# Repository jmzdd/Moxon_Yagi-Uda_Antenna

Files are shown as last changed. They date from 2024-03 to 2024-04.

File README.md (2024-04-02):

# <p align="center">Moxon+Yagi Antenna</p>

<p align="center">⚠实验性：天线尚未经过矢量网络分析仪测量，仅通过MMANA-GAL仿真。</p>
<p align="center">😮复刻有风险，制作需谨慎🤭</p>

## 一、项目背景

&emsp;&emsp;本天线设计参考了“Moxon-Yagi Satellite Antenna by DUIAU (based LY3LP's design)”，感谢DU1AU和LY3LP两位前辈的贡献，原设计图如下：

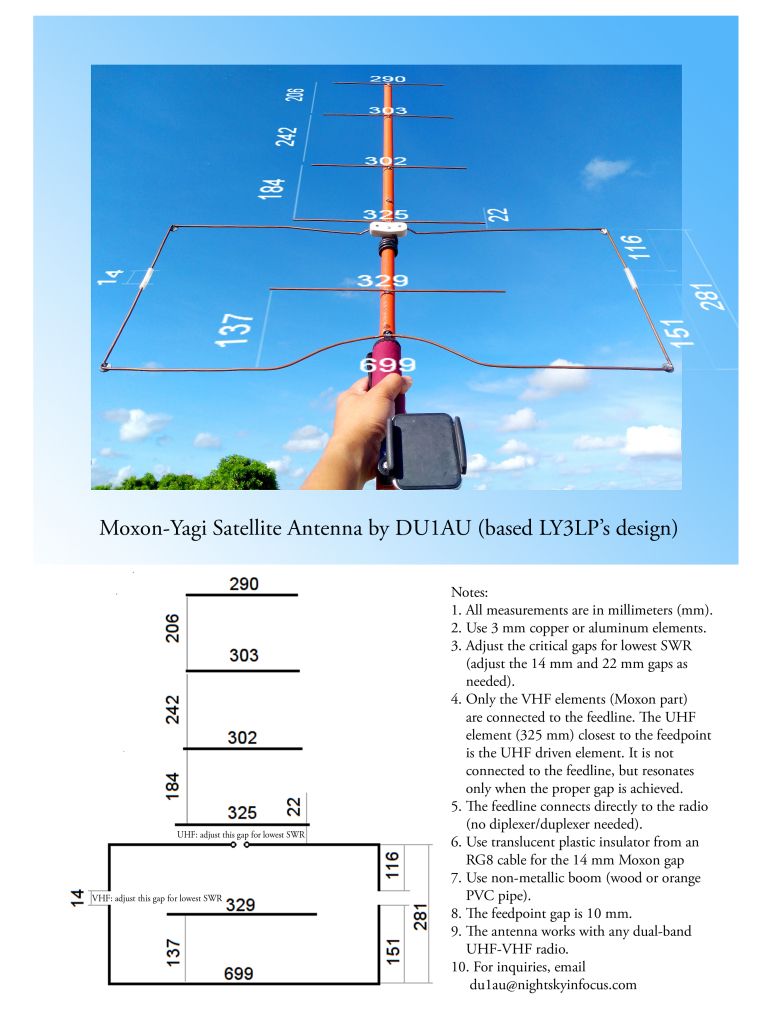
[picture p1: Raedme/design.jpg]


&emsp;&emsp;由于本人手上只有直径1.25mm的铜线作为振子，因此需要对天线的尺寸重新设计。这里我选择使用MMANA-GAL软件对天线进行仿真。花了一两天时间在B站熟悉和理解软件的使用，最后根据软件的仿真结果制作出了成品。

## 二、设计过程

### 2.1 设计思路
&emsp;&emsp;因为是UV双段天线，因此要求天线的中心频率在常用的两个频段：145MHz与435MHz。使用软件对该天线进行仿真，在结构不变的前提下，我修改了振子的长度与各振子之间的间距，最终得出了想要的结果。

&emsp;&emsp;先使用Moxon天线计算器计算莫克森部分，确定其振子的尺寸。由于没有找到合适的八木计算器，无法直接计算八木部分的振子尺寸和间距，遂在确定了莫克森振子尺寸之后在MMANA-GAL软件内建模仿真，通过不断调整八木振子的长度和距离，反复计算其在435MHz时的阻抗和驻波比，最终确定其尺寸和距离。

### 2.2 MMANA-GAL软件仿真

+ 建立天线模型：
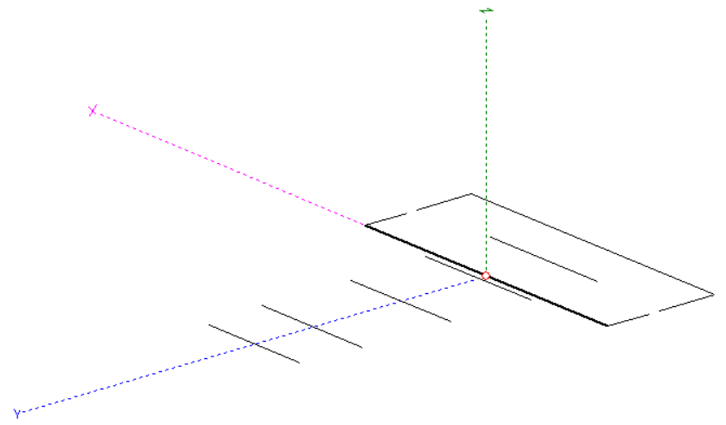
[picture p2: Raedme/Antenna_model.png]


+ 调整八木天线的振子长度和距离：
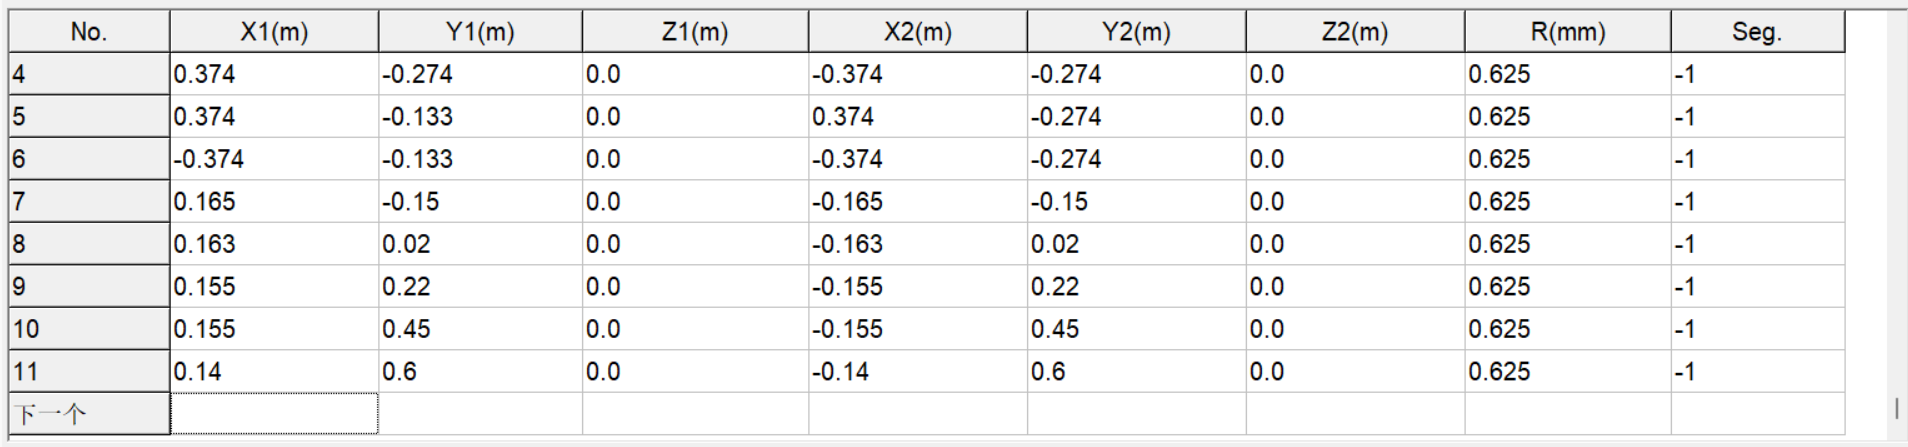
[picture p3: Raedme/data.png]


+ 计算天线阻抗以及驻波比：
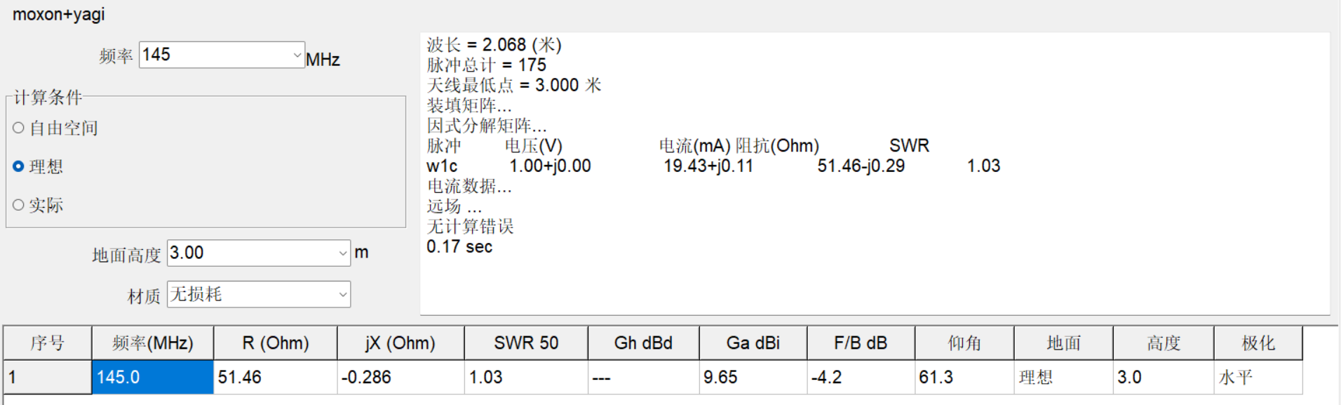
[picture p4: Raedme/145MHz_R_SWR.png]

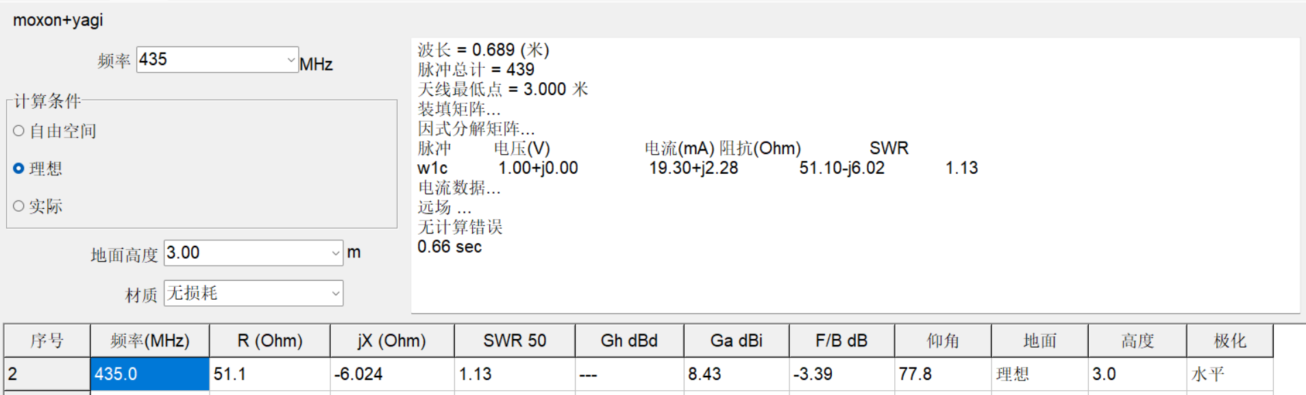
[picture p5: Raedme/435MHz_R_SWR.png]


+ 145MHz与435MHz的远场图：
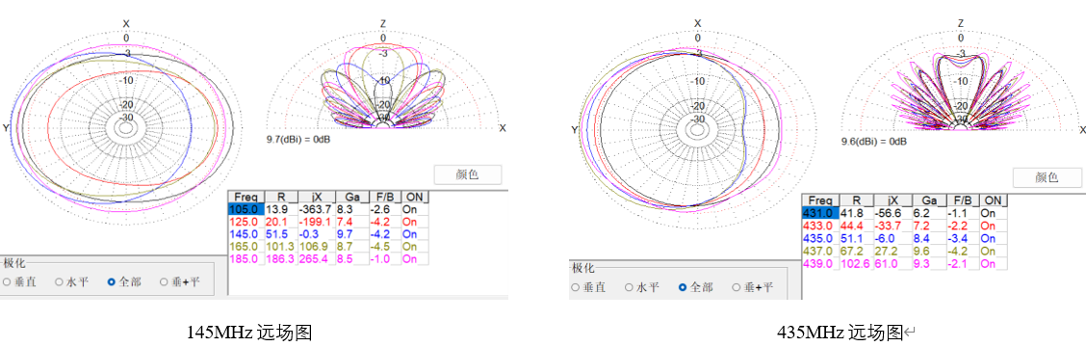
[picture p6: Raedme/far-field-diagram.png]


&emsp;&emsp;由于理论知识欠缺的实在多，在设计过程中遇到的问题大多交给Gemini帮忙给出建议，例如：要解决天线阻抗偏小的问题，可以采取以下措施：
+ 增加天线的尺寸。天线的尺寸越大，天线的输入阻抗就越高。
+ 缩短馈电点的长度。馈电点的长度越短，天线的输入阻抗就越高。
+ 添加串联电感。串联电感可以提高天线的输入阻抗。

&emsp;&emsp;经过调整后，软件显示天线在145MHz的时候，其阻抗为51.46欧姆，驻波比为1.03;当频率为435MHz时，其阻抗为51.1欧姆，驻波比为1.13。

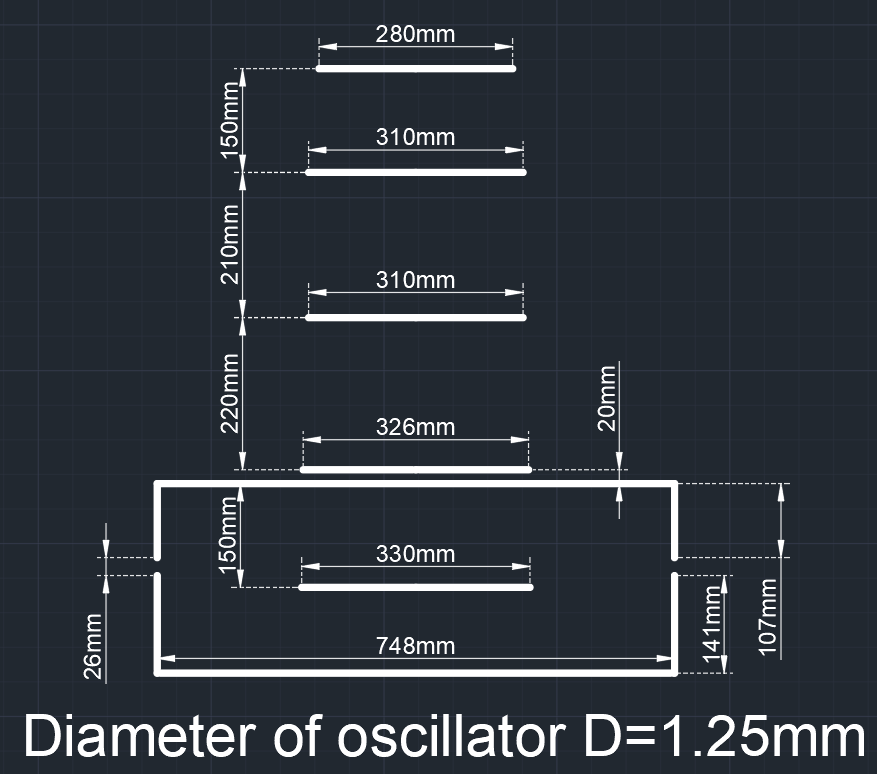
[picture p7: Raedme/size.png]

&emsp;
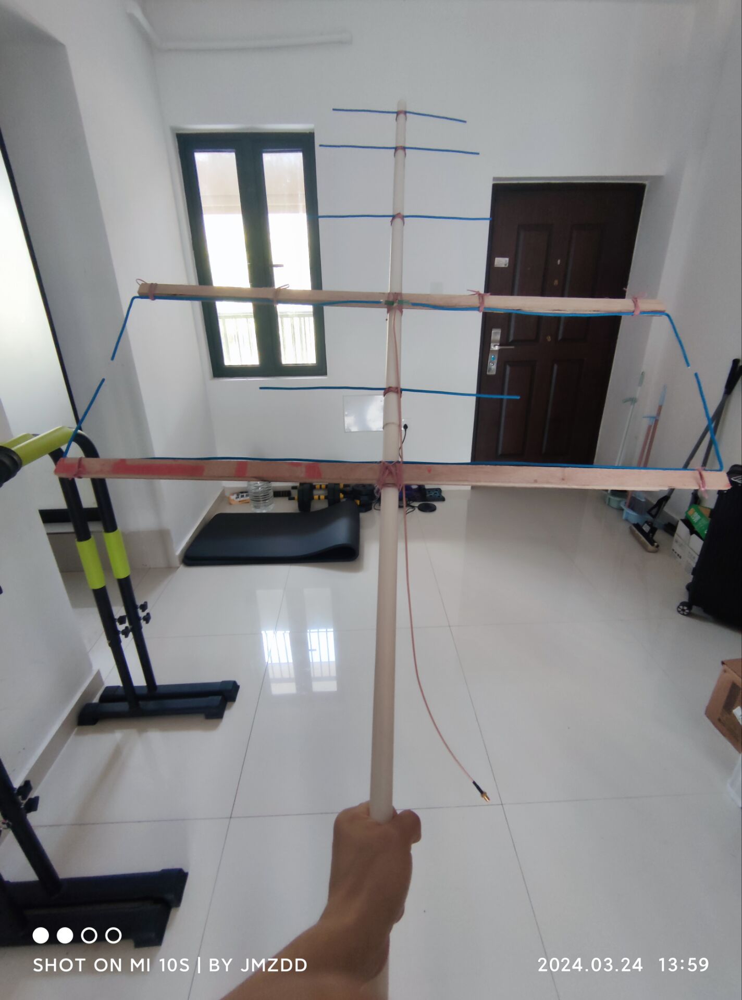
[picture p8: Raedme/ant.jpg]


## 三、文件说明
&emsp;&emsp;仓库内包含了我所使用的仿真软件安装包以及所有的仿真结果，软件资源来源自互联网。现对仿真文件进行说明：

| 文件名 | 说明  |
|:---:| :---:|
| moxon+yagi_d1.25mm.maa | 振子直径为1.25mm |
| moxon+yagi_d2mm.maa | 振子直径为2mm |
| moxon+yagi_d3mm.maa | 振子直径为3mm |

&emsp;&emsp;软件在使用过程中可能会出现“点击仿真不出结果”的情况，我没有找到原因。如果有知道原因的同学，欢迎联系我~

&emsp;&emsp;和老师交流期间做了一些框图文档啥的，存电脑也是浪费，顺带着一起上传了。

## 四、测试过程

&emsp;&emsp;⏰提示：在与学院老师的交流中得知，手台发射的信号属于调频信号，SDR瀑布图内看到的“多个信号”是正常的。如果要测量天线的中心频率，需要用单频信号来测，发射单纯435MHz的信号，在接收的时候才能判断是否是中心频率。（2024/3/20）

&emsp;&emsp;~~由于手上没有设备，因此使用了RTL-SDR进行测试，其中145MHz不明显，435MHz瀑布图如下：~~
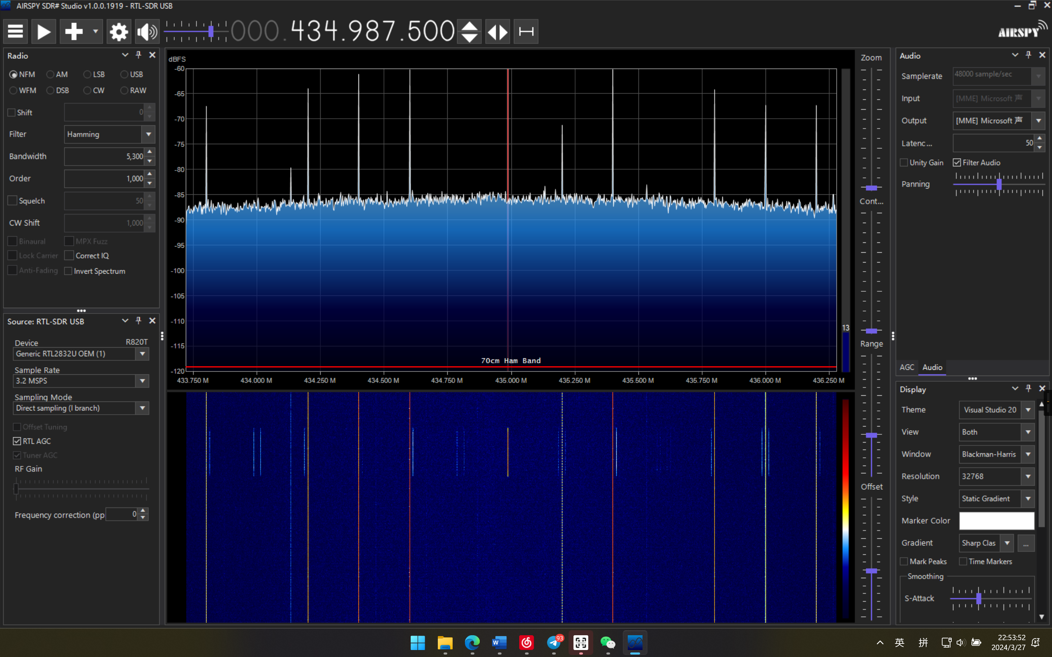
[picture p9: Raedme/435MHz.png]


## 五、制作材料
全天线制作成本为5.3元（可以说非常丐版，挑战全网最低成本天线）

来自食堂工地：
+ 天线支架：PVC水管+木条
+ 天线振子：直径为1.25mm的单股铜线
+ 连接固定：工地纸箱的打包带

淘宝自购：
+ 馈线：RG316，SMA外螺内孔，长度0.8m（5.3元）

## 六、参考资料
### 6.1 仿真软件学习
+ <a href="https://www.qsl.net/bv3fg/ant/MMANA-GAL_manual_zh-TW_20211206-01.pdf">【MMANA-GAL_manual_zh-TW.pdf】</a>
+ <a href="https://www.bilibili.com/video/BV14J411Q7TQ/?vd_source=4c90b194142aa9512e6e97d2155ada5d">【宅台长】天线设计软件MMANA-GAL介绍</a>
+ <a href="https://www.bilibili.com/video/BV12Z4y1B7dj/?vd_source=4c90b194142aa9512e6e97d2155ada5d">【业余无线电·天线仿真】MMANA-GAL仿真：莫克森天线应该怎样调整</a>
### 6.2 天线计算器
+ <a href="https://upall.cn/example/moxon/">【天线计算器】</a>
### 6.3 调试与制作
+ <a href="https://www.hellocq.net/forum/read.php?tid=374264">DIY“莫克森+八木”UV双段天线</a>
+ <a href="https://www.bilibili.com/video/BV19v411T7gT/?vd_source=4c90b194142aa9512e6e97d2155ada5d">自己做一根UV段八木天线连接国际空间站转发器能成功吗？</a>

希望能够对看到这份文档的朋友提供一些小帮助，73~

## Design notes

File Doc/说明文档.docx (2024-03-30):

Moxon+Yagi-Uda UV双段天线设计说明

⚠实验性：天线尚未经过矢量网络分析仪测量，仅通过MMANA-GAL仿真。

复刻有风险，制作需谨慎

1、 项目背景

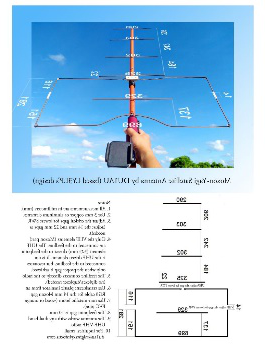
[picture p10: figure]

本天线设计参考了“Moxon-Yagi Satellite Antenna by DUIAU (based LY3LP's design)”，感谢DU1AU和LY3LP两位前辈的贡献，参考设计图见左图。

由于本人手上只有直径1.25mm的铜线作为振子，因此需要对天线的尺寸重新设计。这里我选择使用MMANA-GAL软件对天线进行仿真。花了一两天时间在B站熟悉和理解软件的使用，最后根据软件的仿真结果制作出了成品。

天线设计图

2、 设计过程

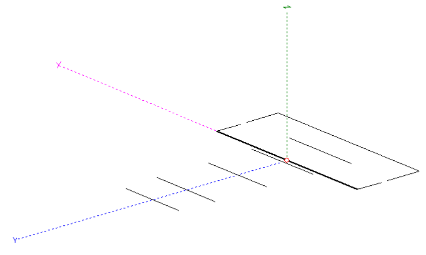
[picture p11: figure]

该天线主要分为莫克森部分以及八木部分，其中莫克森天线设计的中心频率在145MHz，其振子尺寸可以由天线计算器得出。在MMANA-GAL软件内对天线建模，通过调整八木部分的振子长度与间距，仿真其频率在435MHz时，使其天线阻抗接近50Ω，驻波比接近1。

天线模型

经过调整后，软件显示天线在145MHz的时候，其阻抗为51.46欧姆，驻波比为1.03;当频率为435MHz时，其阻抗为51.1欧姆，驻波比为1.13。

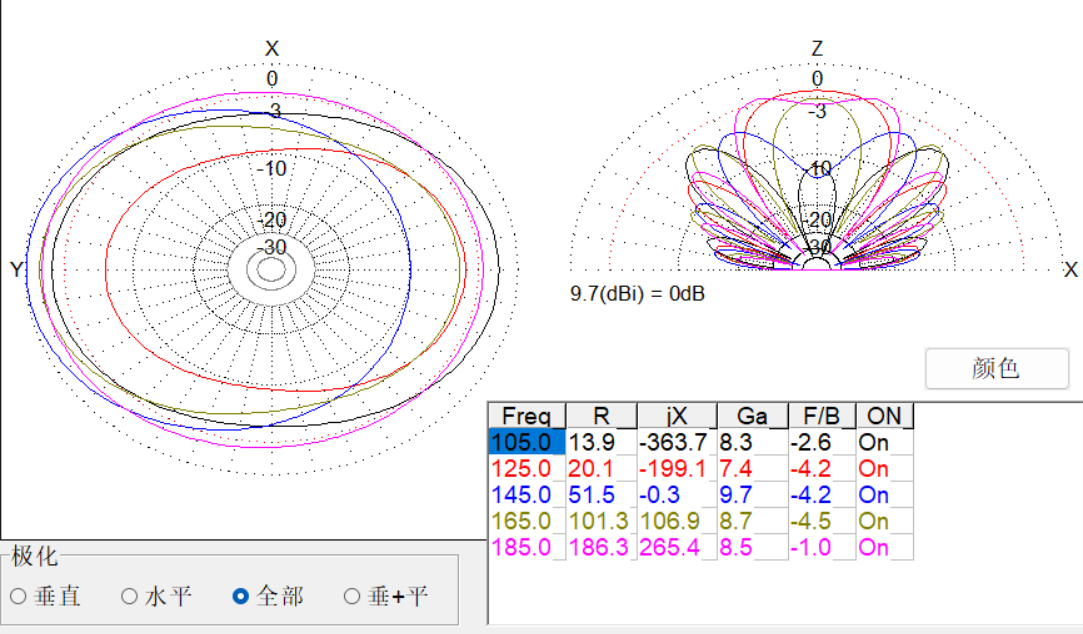
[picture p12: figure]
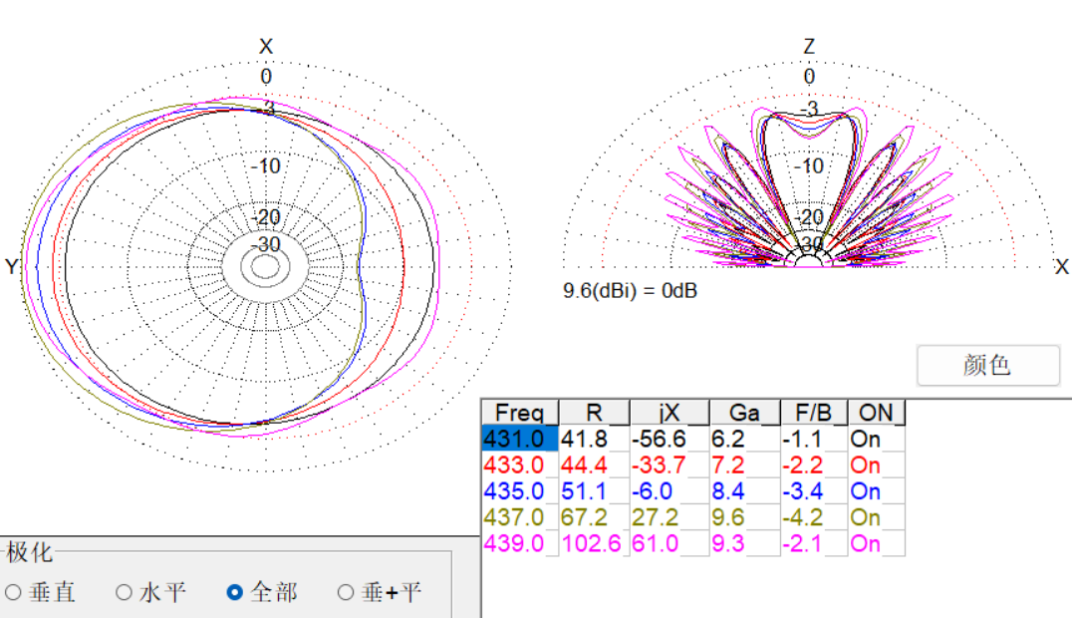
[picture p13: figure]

145MHz远场图 435MHz远场图

3、 项目总结

受制于材料、测试环境的限制以及理论知识的欠缺，该天线的性能仍有很大的优化空间。例如无法测量天线的驻波比以及天线阻抗，RTL-SDR测量到的中心频率并不完全准确等。天线的制作可能存在一定的尺寸误差，振子长度以及距离并不精确。在制作过程中省略了加感线圈，可能会导致天线阻抗误差较大。

4、 参考资料

见仓库Readme.md。

五、制作材料

全天线制作成本为5.3元（可以说非常丐版，挑战全网最低成本天线）

来自食堂工地：

天线支架：PVC水管+木条

天线振子：直径为1.25mm的单股铜线

连接固定：打包带

从淘宝自购：

馈线：RG316，SMA外螺内孔，长度0.8m（5.3元）

6、 制作结果

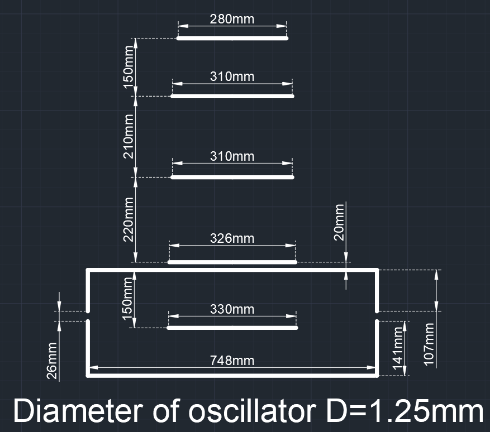
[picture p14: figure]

振子尺寸

7、 项目说明

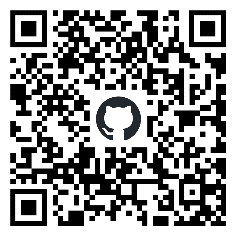
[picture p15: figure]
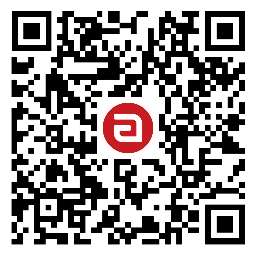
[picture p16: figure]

本项目的仿真文件已存放至Github，同步至Gitee

仓库名：Moxon_Yagi-Uda_Antenna

本人业余无线电电台呼号：BG5VLJ

Github主页：https://github.com/jmzdd

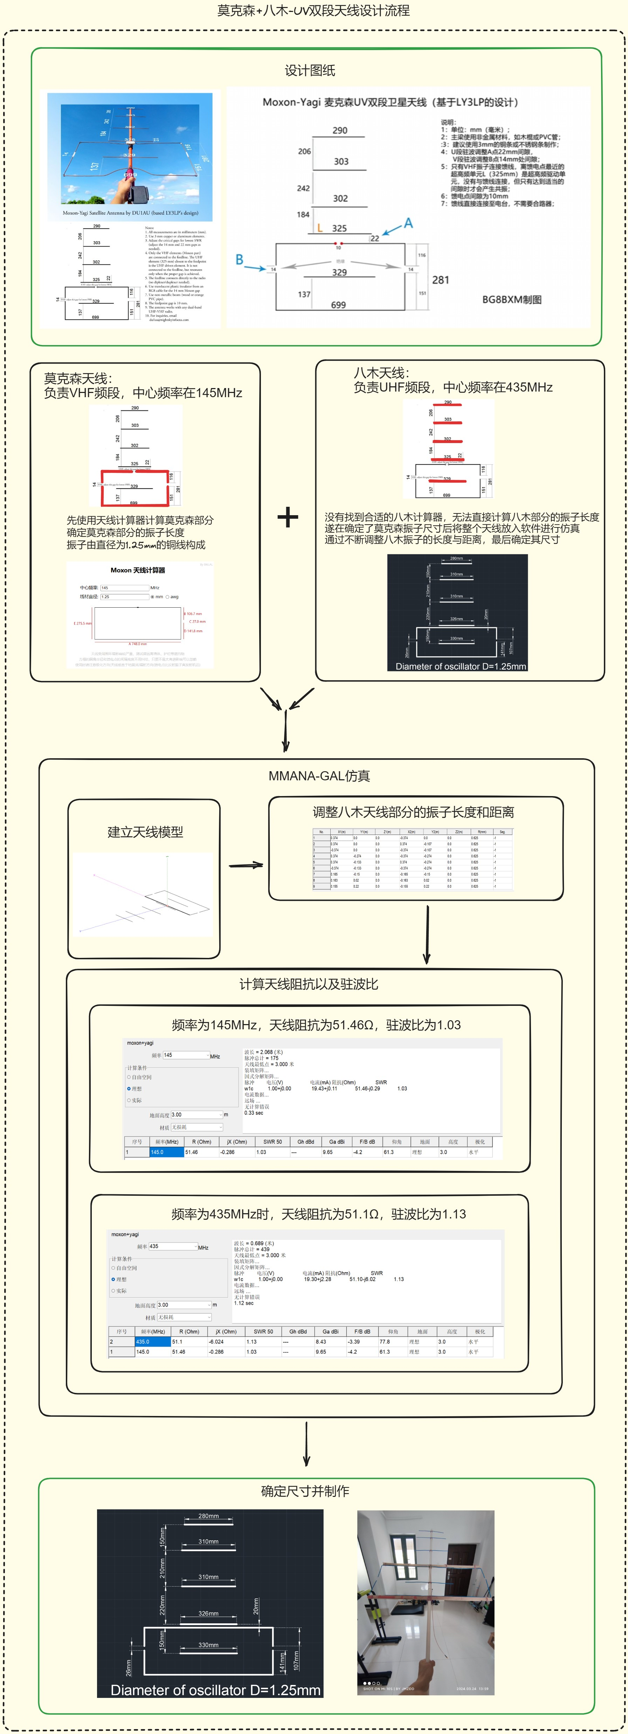
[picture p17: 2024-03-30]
Doc/设计流程.png

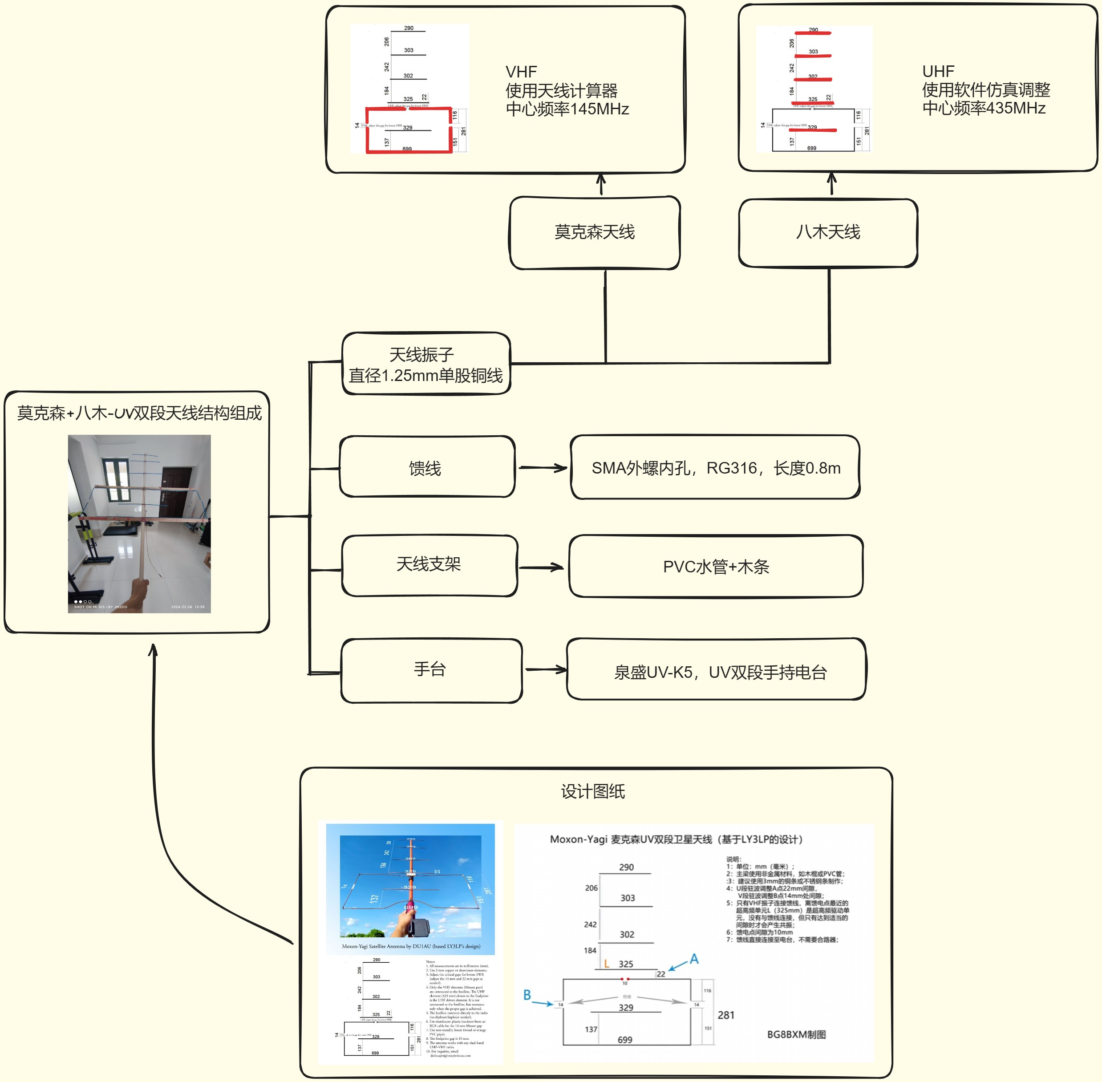
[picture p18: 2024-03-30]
Doc/结构组成.png

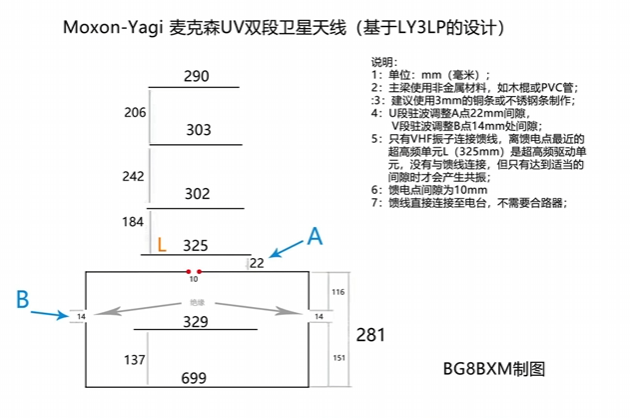
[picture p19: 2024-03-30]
Doc/B站截图.png

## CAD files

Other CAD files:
Doc/成品尺寸.dwg

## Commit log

2024-03-30 Add Files.
    [Drawing1.dwg]
2024-03-30 Update Files.
    [成品尺寸.dwg]
